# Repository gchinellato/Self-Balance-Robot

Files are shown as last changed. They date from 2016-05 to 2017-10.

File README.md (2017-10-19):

# Mr. Robot
_DIY study project_

## Description
Mr. Robot is an amazing TV series \o/, but also it is a DIY project based on the self balance robot concept using sensors to get orientation (pitch, roll and yaw) and PID controller to set the motor speed. Beside that, there are some additional features like wireless controllers by IP or bluetooth clients, computer vision functions like object tracking, video streaming to be used such as Google Cardboard VR for Android application and upcoming features.

## Study topics
This project is based on the following topics:
* Raspberry PI     
* Linux OS
* Python programming
* C++ programming
* Multithread/Multiprocess programming
* Robotics concepts
* IMU sensor fusion
* Computer Vision
* Communication protocols (UART, I2C, SPI, TCP, UDP...)
* Android app (*)
* PyQT

## Item list
* Raspberry Pi 3
* Arduino Nano Atmega328
* PiCam
* Pan/Tilt kit with micro servo 9g
* IMU GY80 10DOF sensor
* Ultrasonic HC-SR04 sensor (*)
* DC gearmotor 29:1 with encoder 12V 365RPM 8KgF.cm 
* Shaft coupler
* Wheels 1/8 buggy
* VNH2SP30 motor driver (H-bridge)
* LiPo battery 3S 11.1 2200mAh
* DC-DC Step down converter
* Bluetooth dongle
* WiFi dongle   
* Google Cardboard VR (*)
* Screws, nuts and bolts
* Acrylic frames 20x15x8cm

(*) TBD 

## External tools
* Opencv: http://opencv.org/
* pySerial: https://github.com/pyserial/pyserial
* PyQt5: https://sourceforge.net/projects/pyqt/
* PyOpenGL: http://pyopengl.sourceforge.net/
* matplotlib: http://matplotlib.org/
* PS3 Bluetooth Controller driver: http://qtsixa.sourceforge.net/
* Servoblaster: https://github.com/richardghirst/PiBits/tree/master/ServoBlaster
* PlatformIO: http://platformio.org/
* Atom IDE: https://atom.io/

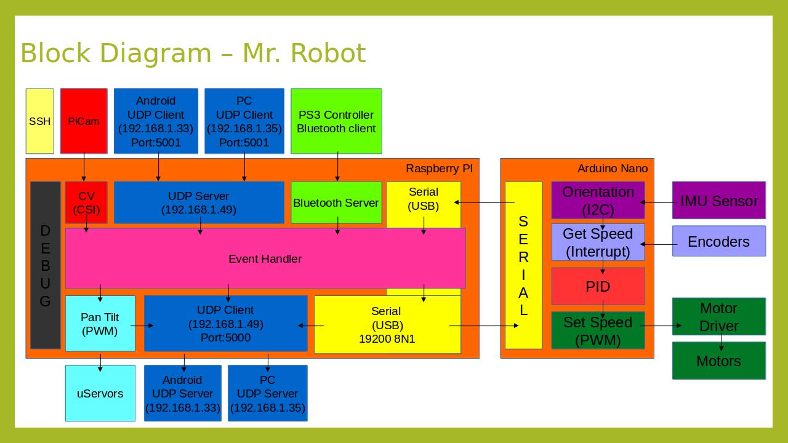
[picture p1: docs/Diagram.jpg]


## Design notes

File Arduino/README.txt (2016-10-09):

# Arduino Nano

Instantiate Motors objects
Instantiate Encoder objetcs
Instantiate PID objects
Instantiate IMU objects (Accel, Gyro, Magno, Barom)

setup()
{
    Configure serial
    Configure interrup pins
    Set configuration
}

loop()
{
    Read serial trace
    Read sensors
    Sensor fusion (Euler angles)   
    Update speeds
    Compute speed PID
    Check angle
    Define PID mode
    Compute angle PID
    Motor set speed
    Send serial trace  
}

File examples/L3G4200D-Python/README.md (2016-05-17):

L3G4200D-Python
===============

L3G4200D Gyro interface in python, using I2C.

Currently, this code opens port i2c-1 in /dev and imports raw data(signed int) of each gyro axis.
you must have python installed "apt-get install python"
in command line do "python gyro.py" to stream raw axis data from the gyro. the readings are noisy, and that's normal.

you should get something like this:

        -1        -14          6
         4        -15          5
        -1        -15         10
        -4        -19          4
        -2        -15         11
         2        -19          7
         1        -17         10
         8        -15         10
         5        -16          7
         2        -17          6
         0        -18         10
        -2        -16         14

you can type "python gyro.py > data.tsv", then ctrl C to stop. take data.tsv, open it in MS Excel
or equivelant, and plot the data to visualise the gyro movements.

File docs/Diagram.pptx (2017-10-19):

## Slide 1

Mr. Robot

Self Balance Robot

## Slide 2

Block Diagram – Mr. Robot

SSH

D
E
B
U
G

PiCam

CV
(CSI)

Android
UDP Client
(192.168.1.33)
Port:5001

PC
UDP Client
(192.168.1.35)
Port:5001

PS3 Controller
Bluetooth client

Bluetooth Server

Raspberry PI

Event Handler

UDP Server
(192.168.1.49)

Serial
(USB)

Serial
(USB)
19200 8N1

Arduino Nano

Orientation
(I2C)

Get Speed
(Interrupt)

PID

Set Speed
(PWM)

S
E
R
I
A
L

IMU Sensor

Encoders

Pan Tilt
(PWM)

UDP Client
(192.168.1.49)
Port:5000

Motor
Driver

uServors

Android
UDP Server
(192.168.1.33)

PC
UDP Server
(192.168.1.35)

Motors

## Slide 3

Block Diagram – Wifi Monitor

RPI
UDP Client
(192.168.1.49)

PC

UDP Server
(192.168.1.35)
PORT:5000

UDP Client
(192.168.1.49)
Port:5001

GUI
PyQT

Real time graph
Matplotlib

3D Model
OpenGL

RPI
UDP Server
(192.168.1.49)

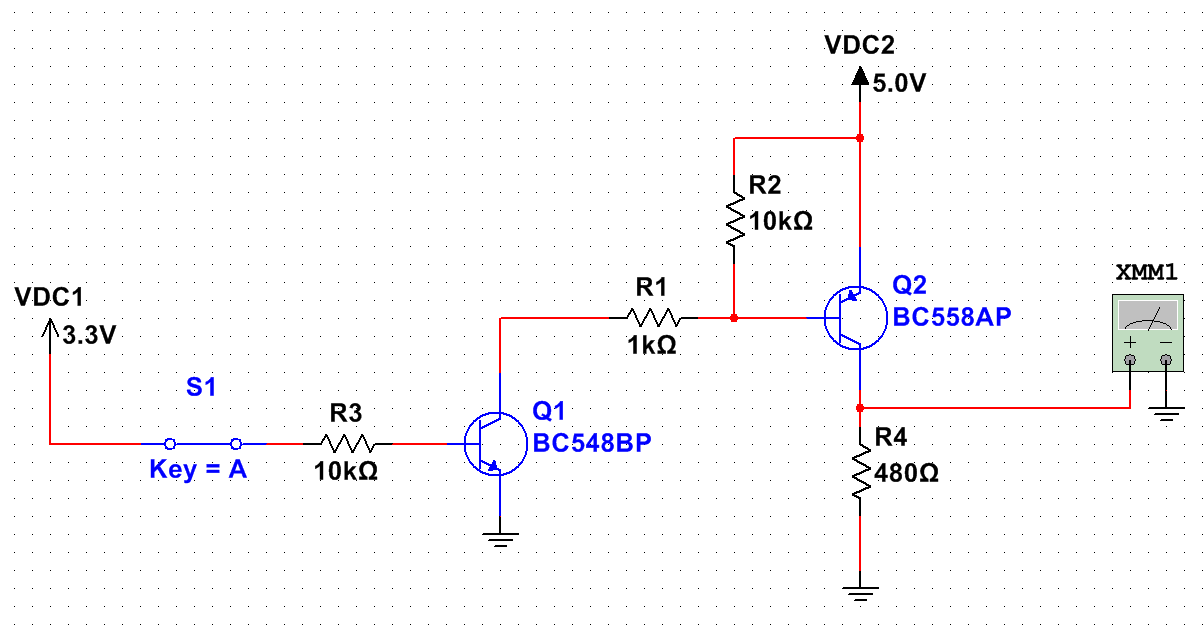
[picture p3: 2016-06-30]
docs/transistor-switch.png

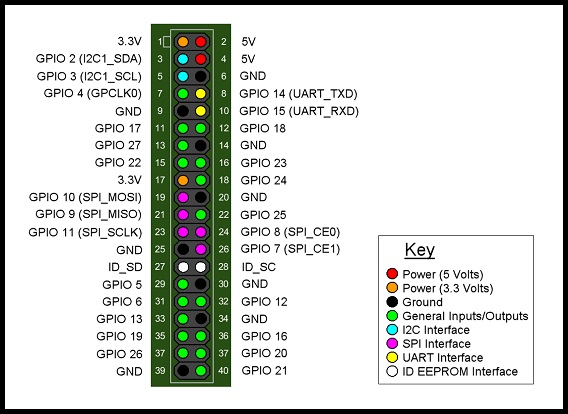
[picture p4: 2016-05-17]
docs/raspberrypi2-gpio-mapping.jpg

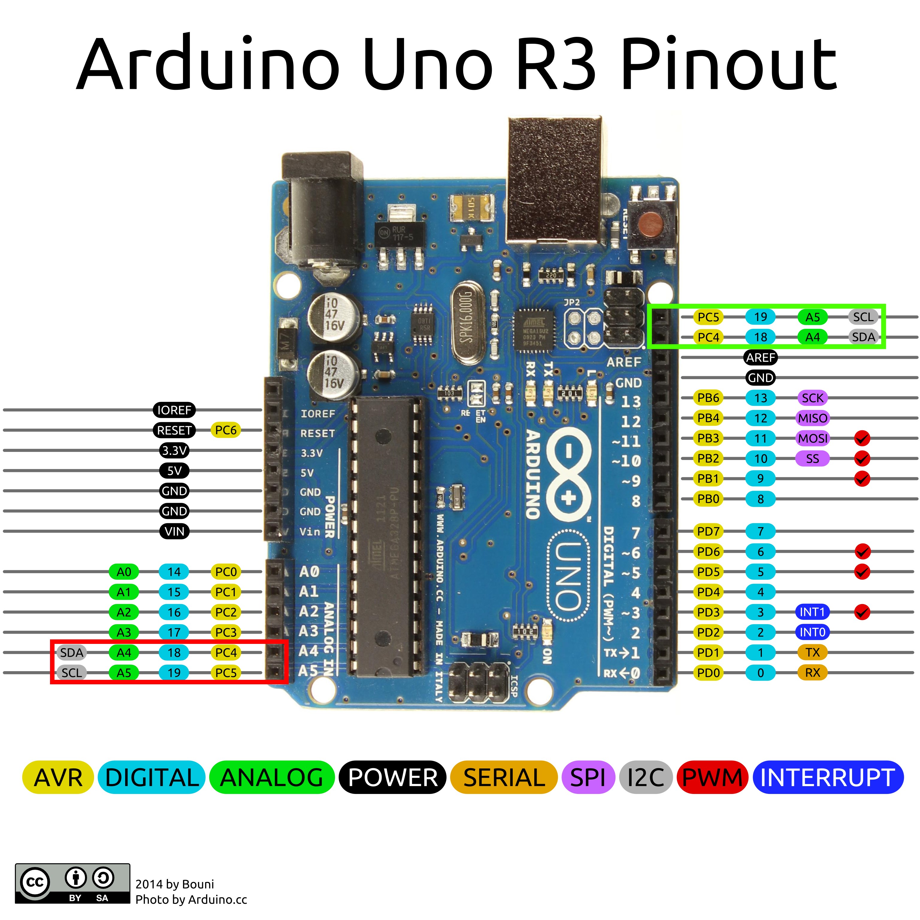
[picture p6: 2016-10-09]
docs/arduino-uno-r3-gpio-mapping.jpg

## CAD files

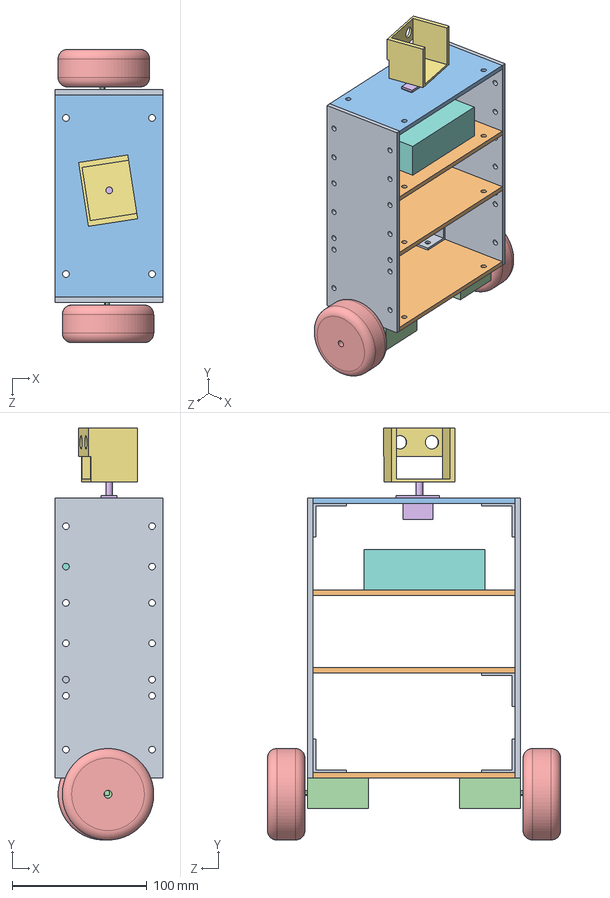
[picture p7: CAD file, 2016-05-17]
3D Model/Frame.SLDASM
80.0 x 306.2 x 218.0 mm
Placa-lateral x 2
Placa-inferior x 3
Placa-superior
motor x 2
roda x 2
micro-servo
pan-tilt
rp2
Suporte-L x 5

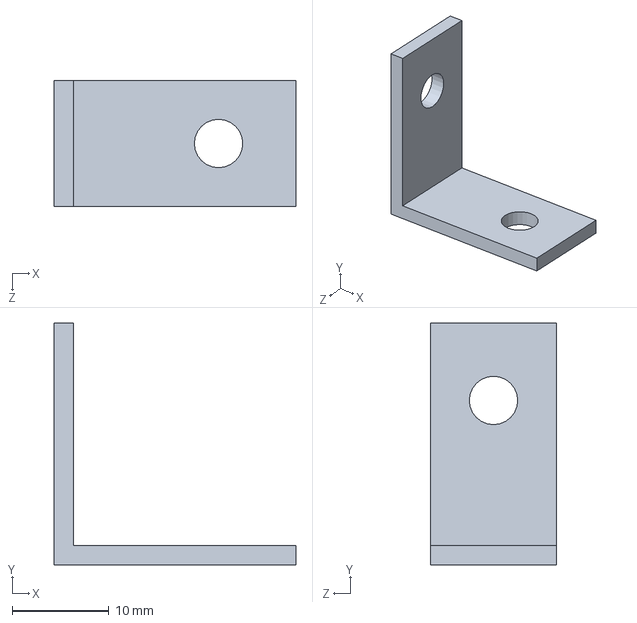
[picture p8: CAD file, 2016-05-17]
3D Model/Suporte-L.SLDPRT
25.0 x 25.0 x 13.0 mm

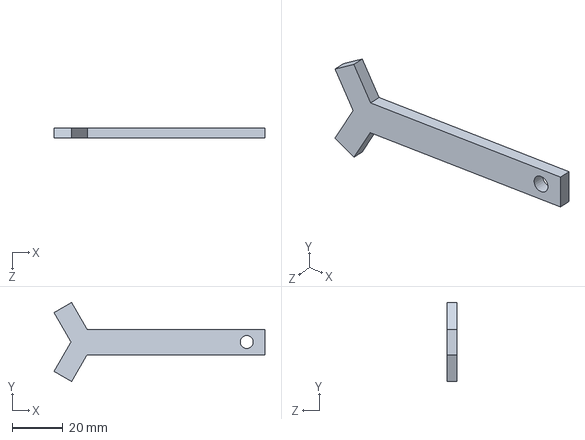
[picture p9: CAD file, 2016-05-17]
3D Model/arm.SLDPRT
82.9 x 31.1 x 4.00 mm

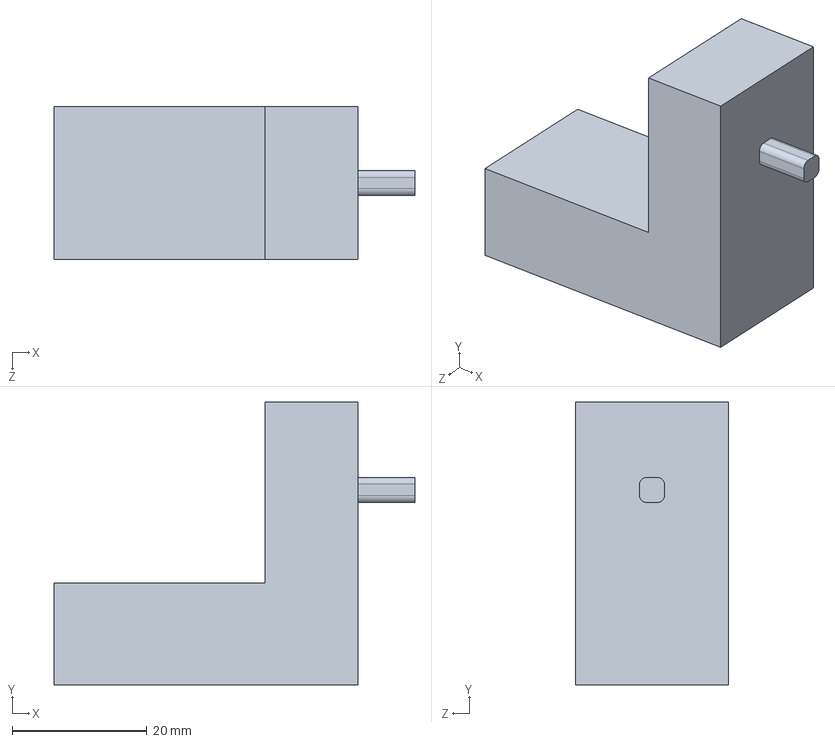
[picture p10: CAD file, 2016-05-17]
3D Model/motor.SLDPRT
53.6 x 42.0 x 22.7 mm

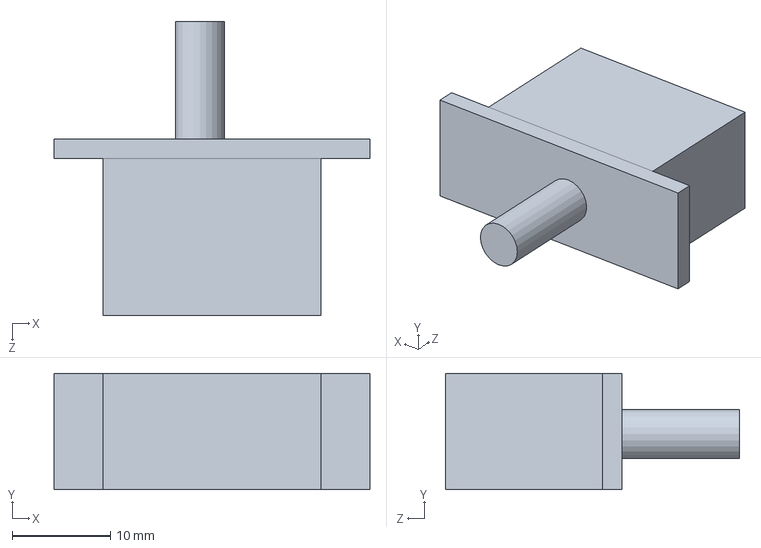
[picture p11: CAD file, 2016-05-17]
3D Model/micro-servo.SLDPRT
32.2 x 11.8 x 30.0 mm

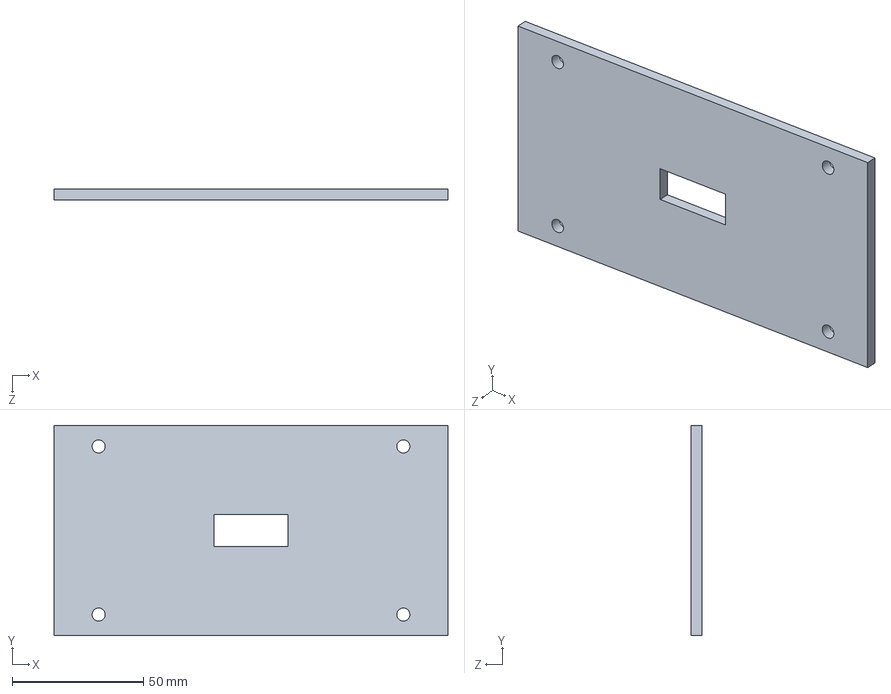
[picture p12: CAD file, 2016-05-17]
3D Model/Placa-superior.SLDPRT
150.0 x 80.0 x 4.00 mm

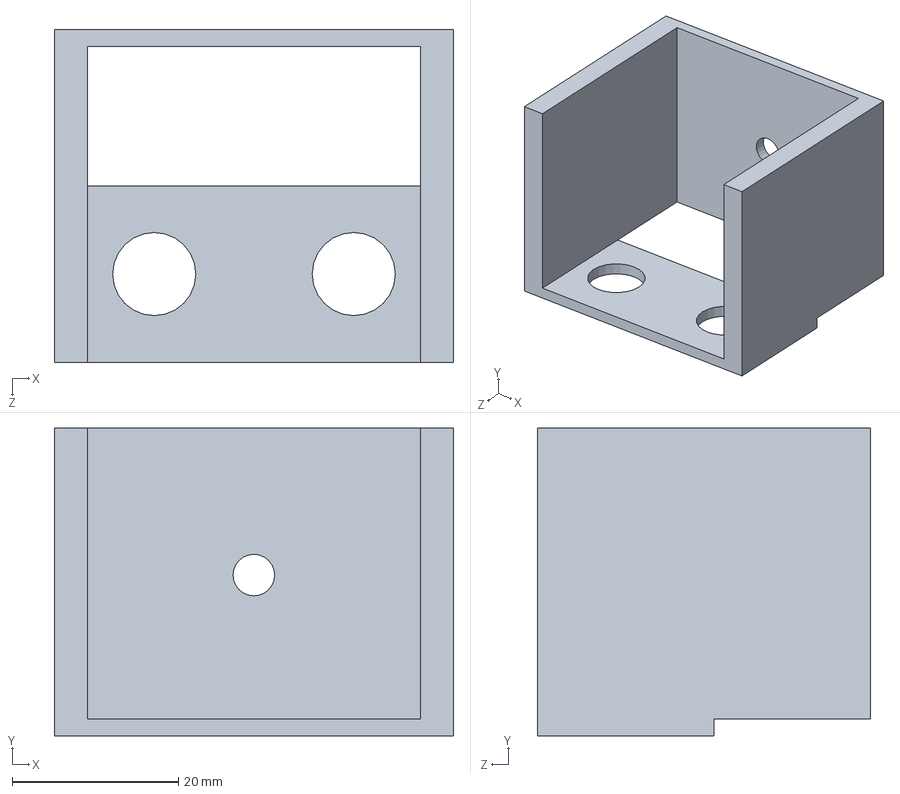
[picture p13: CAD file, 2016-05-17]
3D Model/pan-tilt.SLDPRT
48.0 x 37.0 x 40.0 mm

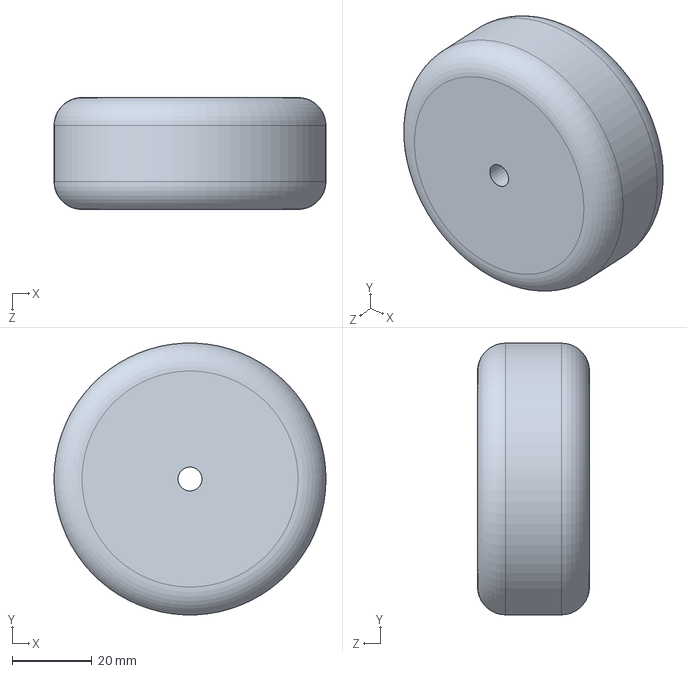
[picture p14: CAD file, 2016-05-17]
3D Model/roda.SLDPRT
68.0 x 67.9 x 28.0 mm

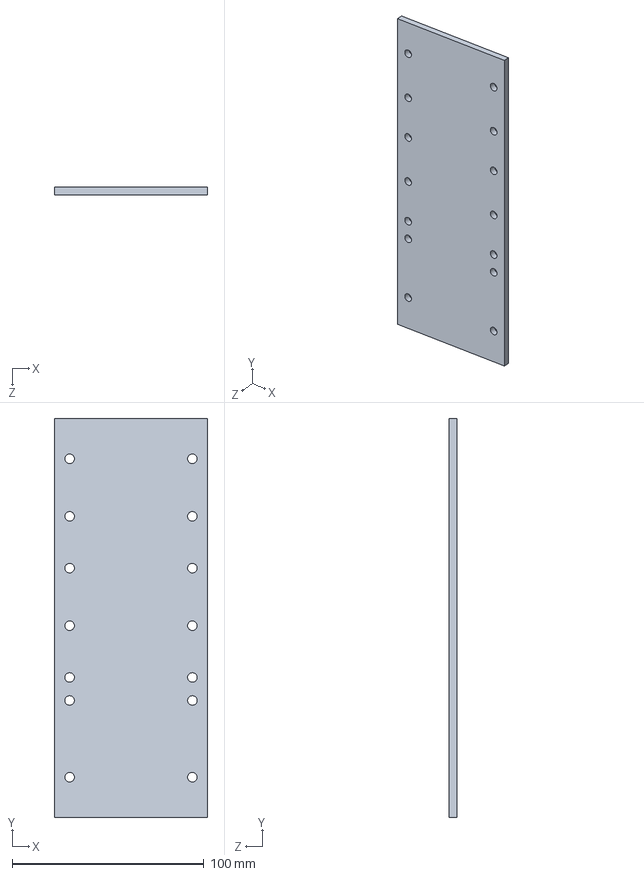
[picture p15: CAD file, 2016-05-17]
3D Model/Placa-lateral.SLDPRT
80.0 x 208.0 x 4.00 mm

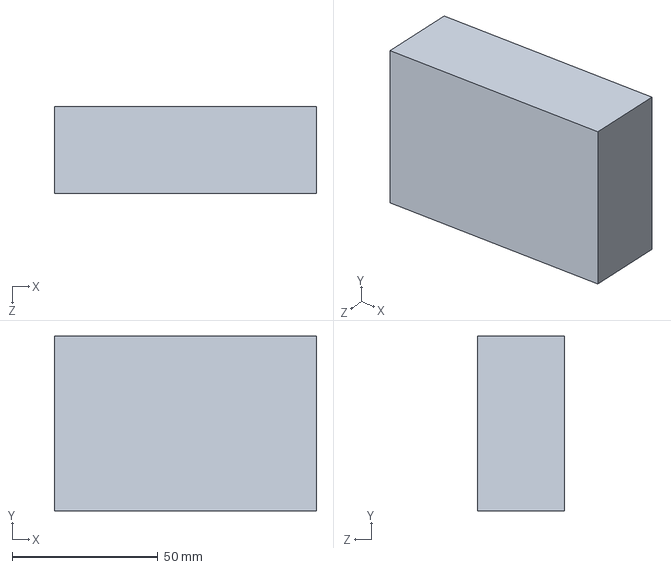
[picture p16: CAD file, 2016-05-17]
3D Model/rp2.SLDPRT
90.0 x 60.0 x 30.0 mm

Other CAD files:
3D Model/Placa-inferior.SLDPRT
3D Model/Placa-inferior.SLDDRW
3D Model/Placa-lateral.SLDDRW
3D Model/Placa-superior.SLDDRW

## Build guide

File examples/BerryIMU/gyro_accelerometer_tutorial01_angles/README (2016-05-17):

* Developed by Mark Williams
* Created December 2014

This program will enable your Raspberry Pi to read the values from a gyroscope and accelerometer and convert them to usable angles.
Go here for more information;

http://ozzmaker.com/2014/12/11/berryimu/

Compile with;
gcc -o gyro_accelerometer_tutorial01 -l rt gyro_accelerometer_tutorial01.c -lm

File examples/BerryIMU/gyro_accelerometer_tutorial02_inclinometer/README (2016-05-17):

* Developed by Mark Williams
* Created December 2014

This program is used to create an Inclinometer using a Raspberry Pi and an IMU

http://ozzmaker.com/2014/12/12/inclinometer-using-raspberry-pi-imu/

Compile with;

gcc -o gyro_accelerometer_tutorial02 -lm gyro_accelerometer_tutorial02.c `sdl-config --cflags` `sdl-config --libs` -lSDL_image -lSDL_gfx

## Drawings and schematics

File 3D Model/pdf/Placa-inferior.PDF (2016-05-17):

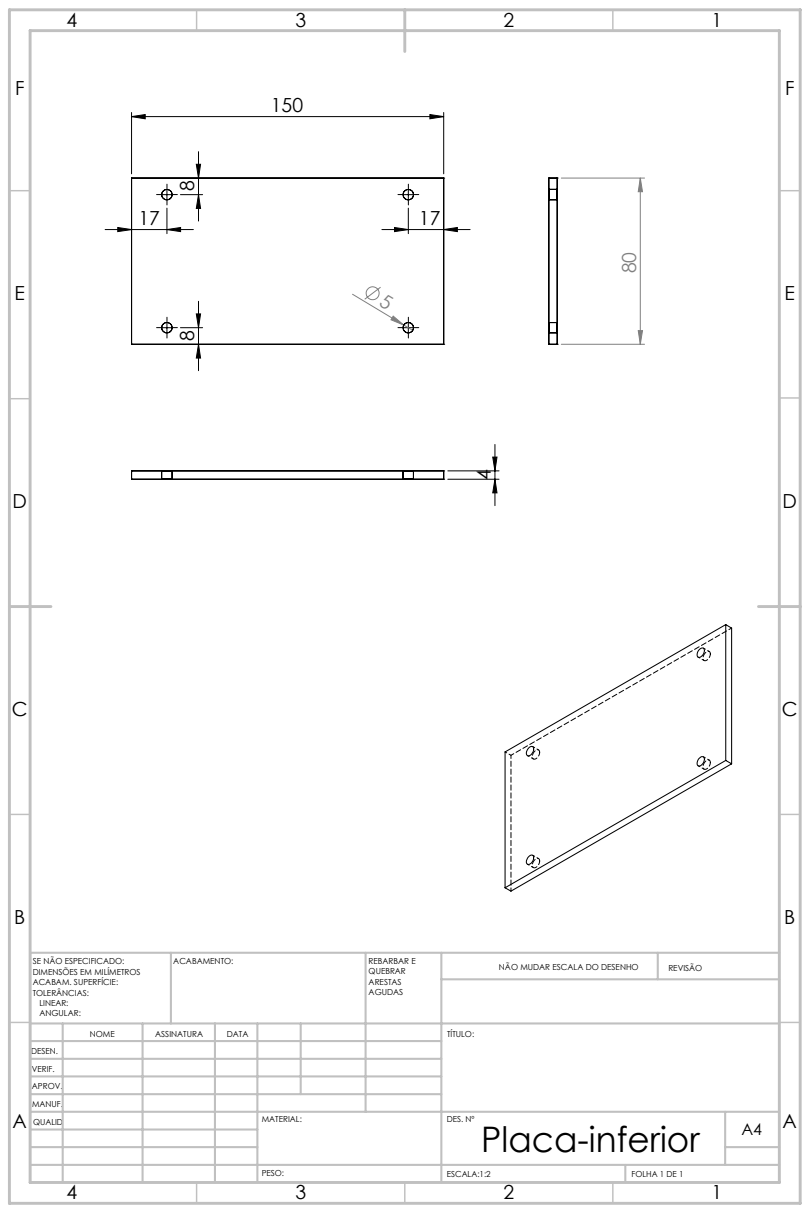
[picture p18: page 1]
ACABAMENTO:; REBARBAR E; NÃO MUDAR ESCALA DO DESENHO; REVISÃO; ESCALA:1:2; FOLHA 1 DE 1

SE NÃO ESPECIFICADO:
DIMENSÕES EM MILÍMETROS
ACABAM. SUPERFÍCIE:
TOLERÂNCIAS:
LINEAR:
ANGULAR:

NOME | ASSINATURA | DATA | | | | TÍTULO:

DESEN.
VERIF.
APROV.
MANUF.
QUALID | | | | MATERIAL: | DES. Nº Placa-inferior | A4

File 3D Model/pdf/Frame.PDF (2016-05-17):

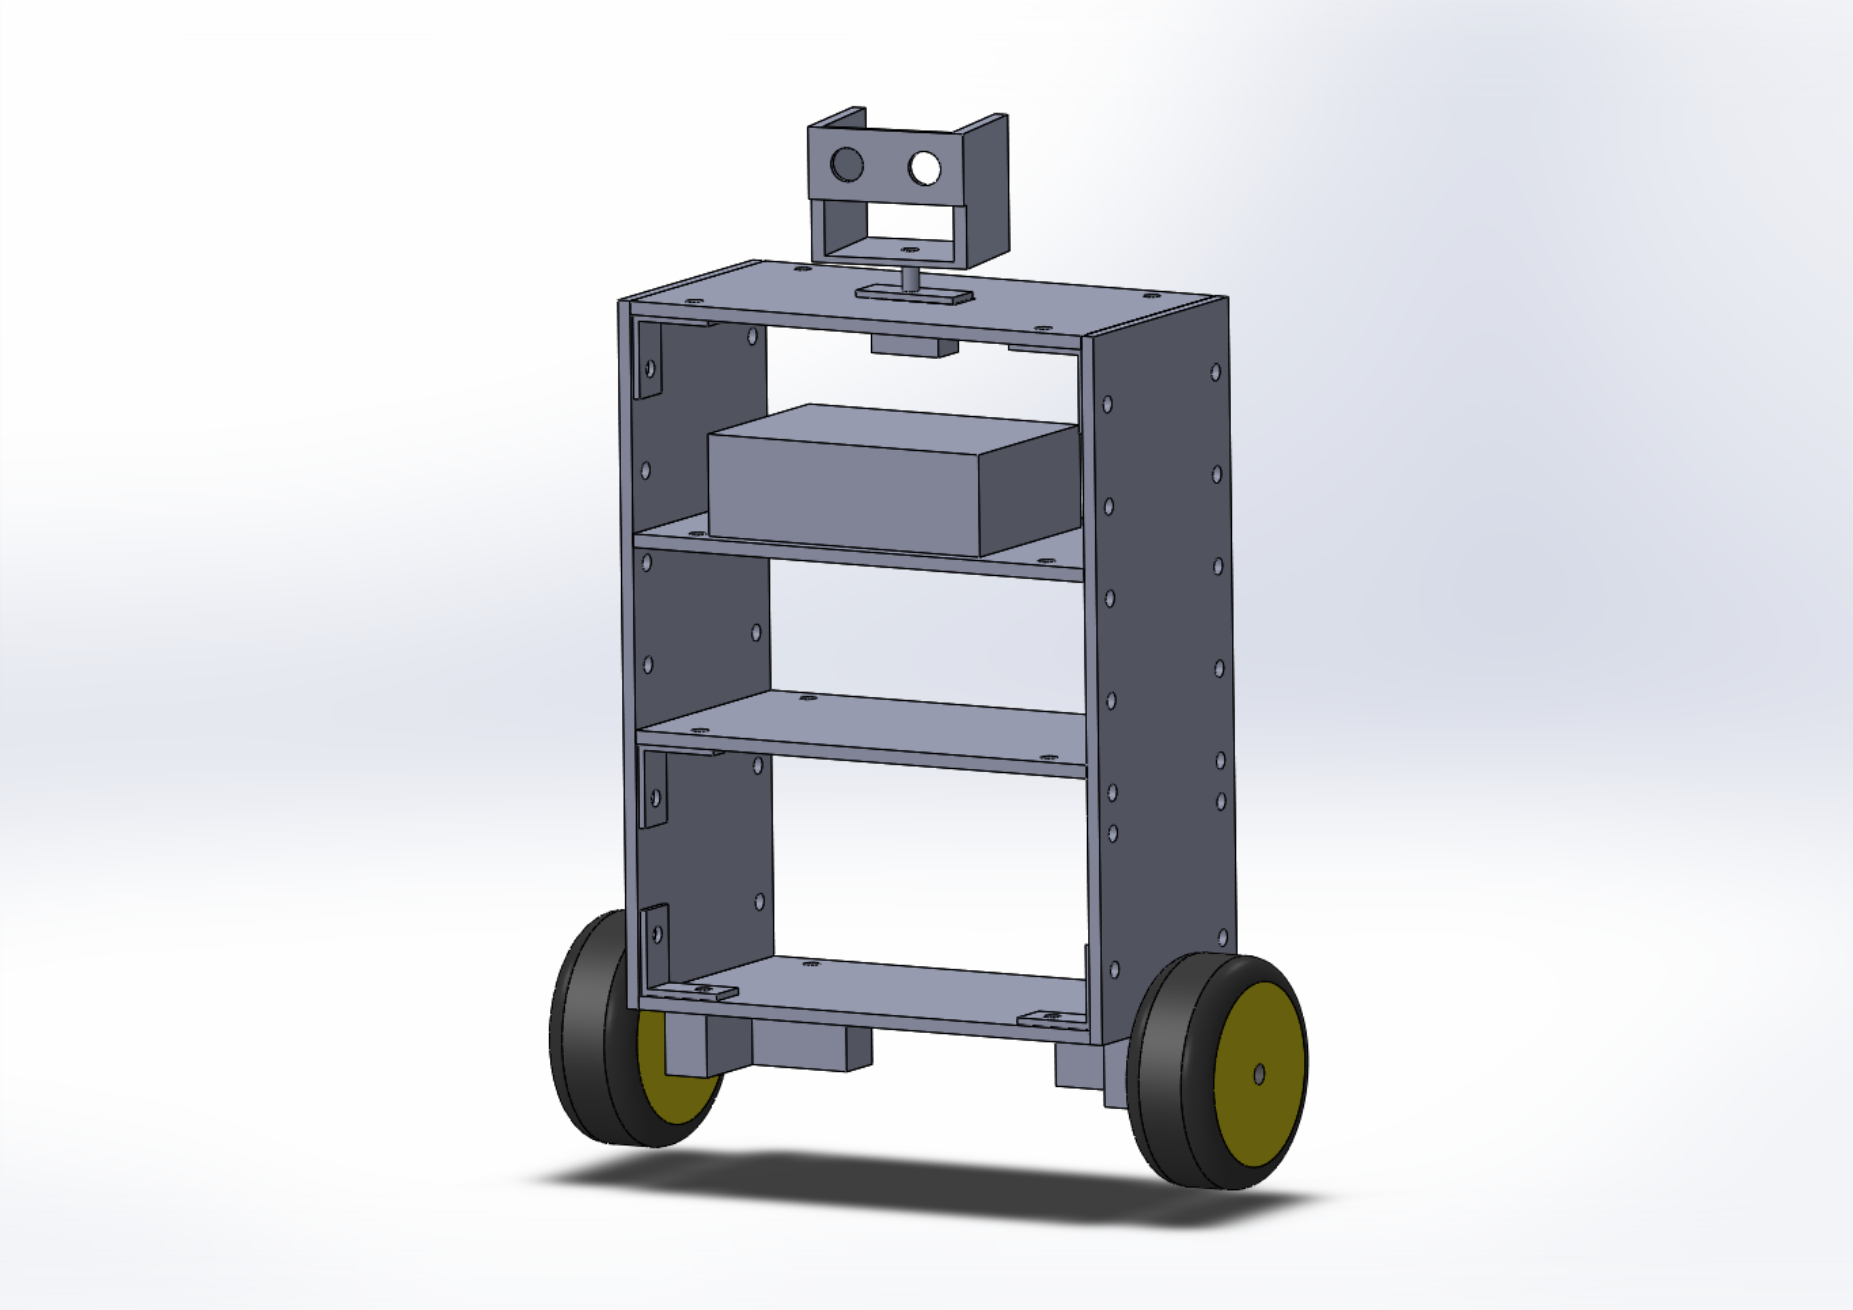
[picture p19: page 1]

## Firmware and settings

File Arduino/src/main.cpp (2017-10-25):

/**
*************************************************
* @Project: Self Balance
* @Platform: Arduino Nano ATmega328
* @Description: Main thread
* @Owner: Guilherme Chinellato
* @Email: guilhermechinellato@gmail.com
*************************************************
*/

#include "Arduino.h"
#include <string.h>
#include <Wire.h>
#include "IMU/GY80.h"
#include "Motion/Motor/motor.h"
#include "Motion/Encoder/encoder.h"
#include "Motion/PID/PID.h"
#include "main.h"

Configuration configuration;
UserControl userControl = {0, 0};

// PID variables
float anglePIDSetpoint, anglePIDInput, anglePIDOutput;
float speedPIDInput, speedPIDOutput, speedPIDSetpoint;

float lastDistance1 = 0, lastDistance2 = 0;

// start and stop flag
boolean started = false;

//PID objects
PID speedPID;
PID anglePID;
PIDTuning activePIDTuning = CONSERVATIVE;

//Motors objects
Motor motor1(PWM1_PIN,CW1_PIN,CCW1_PIN,CS1_PIN);
Motor motor2(PWM2_PIN,CW2_PIN,CCW2_PIN,CS2_PIN);

//Encoder objects
Encoder encoder1(ENCODERA1_PIN,ENCODERB1_PIN);
Encoder encoder2(ENCODERA2_PIN,ENCODERB2_PIN);

/* interrupt functions for counting revolutions in the encoders */
/*when the callback function is called due an interrup event on pinEncoder1 and pinEncoder2 is true, then is clockwise, if not it is counter-clockwise*/
void encoderISR1()
{
    if(digitalRead(encoder1.pin2)){ encoder1.ticks++; }
    else{ encoder1.ticks--; }
}

void encoderISR2()
{
    if(digitalRead(encoder2.pin2)){ encoder2.ticks++; }
    else{ encoder2.ticks--; }
}

void setConfiguration()
{
    configuration.speedPIDKp = SPEED_KP;
    configuration.speedPIDKi = SPEED_KI;
    configuration.speedPIDKd = SPEED_KD;
    configuration.speedPIDOutputLowerLimit = -10.00;
    configuration.speedPIDOutputHigherLimit = 10.00;
    configuration.anglePIDAggKp = ANGLE_KP_AGGR;
    configuration.anglePIDAggKi = ANGLE_KI_AGGR;
    configuration.anglePIDAggKd = ANGLE_KD_AGGR;
    configuration.anglePIDConKp = ANGLE_KP_CONS;
    configuration.anglePIDConKi = ANGLE_KI_CONS;
    configuration.anglePIDConKd = ANGLE_KD_CONS;
    configuration.anglePIDLowerLimit = ANGLE_LIMIT;
    configuration.calibratedZeroAngle = CALIBRATED_ZERO_ANGLE;
}

void setup()
{
    Serial.begin(SERIAL_BAUDRATE);
    Serial.setTimeout(10);
    while(!Serial) {}

    //Caution: beware to change TIMER0 default register.
    //Millis, delay and other functions uses the same TIMER0 as PWM pin 5 and 6.
    //Check https://arduino-info.wikispaces.com/Arduino-PWM-Frequency
    //define PWM pre-scaler to 3921.16 Hz in TIMER1
    TCCR1B = (TCCR1B & B11111000) | B00000010;

    //interrupt pins
    pinMode(encoder1.pin1, INPUT_PULLUP);
    pinMode(encoder2.pin1, INPUT_PULLUP);
    attachInterrupt(digitalPinToInterrupt(encoder1.pin1), encoderISR1, RISING);
    attachInterrupt(digitalPinToInterrupt(encoder2.pin1), encoderISR2, RISING);

    setConfiguration();

/*
    GY80 imu;
	if (CALIBRATION_MAGNETO == 1)
	{
		Serial.println("MAGNETO/1000.0fMETER CALIBRATION STARTED");
		imu.magCalibration();
		Serial.println("CALIBRATION FINISHED");
	}
*/
}

void loop()
{
    float velocity1=0, velocity2=0;
    float distance1, distance2;
    int command = 0;
    String msg;
    char buff[128];
    char *ret;
    int size;

    GY80 imu;

    while(1)
	{
        timestamp = millis();
        if ((timestamp - timestamp_old) >= DATA_INTERVAL)
		{    
            //convert from ms to sec
            dt = (float)(timestamp - timestamp_old)/1000.0f; 
            timestamp_old = timestamp;

            msg = "";
            //read serial trace
            //(TRACE_BEGIN)(COMMAND),(NUM_PARAM),(PARAM_1),(PARAM_2),(...)(TRACE_END)
            while(Serial.available() > 0)
            {
                // read the incoming byte:
                msg = Serial.readString();
                //Serial.print(msg);
            }

            if(msg != ""){
                //valid packet? Start: #BEGIN# End: #END#\r\n
                if(msg.startsWith(TRACE_BEGIN) && msg.endsWith(TRACE_END+String("\r\n"))){
                    //remove TRACE_BEGIN
                    msg.remove(0,7);

                    //remove TRACE_END\r\n
                    msg.remove(msg.length()-7,7);

                    //conver75t from string to char array
                    msg.toCharArray(buff, 128);

                    //split string into tokens
                    ret = strtok(buff, ",");

                    //get command
                    command = atoi(ret);
                    //get number of parameters
                    size = int(strtok(NULL, ","));

                    switch (command) {
                        case STARTED:
                            started = atoi(strtok(NULL, ","));
                            //Serial.println("STARTED command: " + String(started));
                            break;
                        case DIRECTION:
                            userControl.direction = atof(strtok(NULL, ","));
                            userControl.direction /= 10;
                            //Serial.println("DIRECTION command: " + String(userControl.direction));
                            break;
                        case STEERING:
                            userControl.steering = atof(strtok(NULL, ","));
                            userControl.steering /= 10;
                            //Serial.println("STEERING command: " + String(userControl.steering));
                            break;
                        case SPEED_PID:
                            configuration.speedPIDKp = atof(strtok(NULL, ","));
                            configuration.speedPIDKi = atof(strtok(NULL, ","));
                            configuration.speedPIDKd = atof(strtok(NULL, ","));
                            //Serial.println("SPEED_PID command: " + String(configuration.speedPIDKp) +","+ String(configuration.speedPIDKi) +","+ String(configuration.speedPIDKd));
                            speedPID.setTunings(configuration.speedPIDKp, configuration.speedPIDKi, configuration.speedPIDKd);
                            break;
                        case ANGLE_PID_AGGR:
                            configuration.anglePIDAggKp = atof(strtok(NULL, ","));
                            configuration.anglePIDAggKi = atof(strtok(NULL, ","));
                            configuration.anglePIDAggKd = atof(strtok(NULL, ","));
                            //Serial.println("ANGLE_PID_AGGR command: " + String(configuration.anglePIDAggKp) +","+ String(configuration.anglePIDAggKi) +","+ String(configuration.anglePIDAggKd));
                            break;
                        case ANGLE_PID_CONS:
                            configuration.anglePIDConKp = atof(strtok(NULL, ","));
                            configuration.anglePIDConKi = atof(strtok(NULL, ","));
                            configuration.anglePIDConKd = atof(strtok(NULL, ","));
                            //Serial.println("ANGLE_PID_CONS command: " + String(configuration.anglePIDConKp) +","+ String(configuration.anglePIDConKi) +","+ String(configuration.anglePIDConKd));
                            break;
                        case ZERO_ANGLE:
                            configuration.calibratedZeroAngle = atof(strtok(NULL, ","));
                            //Serial.println("ZERO_ANGLE command: " + String(configuration.calibratedZeroAngle));
                            break;
                        case ANGLE_LIMITE:
                            configuration.anglePIDLowerLimit = atof(strtok(NULL, ","));
                            //Serial.println("ANGLE_LIMITE command: " + String(configuration.anglePIDLowerLimit));
                            break;
                        default:
                            //Serial.println("Unknown command");
                            break;
                    }
                }
                else{
                    //Invalid packtet
                    //Serial.println("Invalid packtet");
                }
            }

            //read sensors and calculate Euler Angles
			ori = imu.getOrientation(1, dt); //roll pitch yaw
            anglePIDInput = ori[1];

            //update velocity
            //velocity: derivative of position (Pf - Pi)/dt, from cm/ms to m/s
            if(dt > 0)
            {
                distance1 = encoder1.getDistance();
                distance2 = encoder2.getDistance();
                velocity1 = ((distance1 - lastDistance1)*0.01)/(dt/1000.0);
                velocity2 = ((distance2 - lastDistance2)*0.01)/(dt/1000.0);
                lastDistance1 = distance1;
                lastDistance2 = distance2;
            }

            //update motor speed
            motor1.motorSpeed = (float)(encoder1.ticks - encoder1.lastTicks);
            encoder1.lastTicks = encoder1.ticks;
            motor2.motorSpeed = (float)(encoder2.ticks - encoder2.lastTicks);
            encoder2.lastTicks = encoder2.ticks;
/*
            //Compute Speed PID (input is wheel speed. output is angleSetpoint)
            speedPIDInput = (motor1.motorSpeed + motor2.motorSpeed)/2;
            speedPID.setSetpoint(userControl.direction);
            speedPIDOutput = speedPID.compute(speedPIDInput);

            //set angle setpoint and compensate to reach equilibrium point
            anglePID.setSetpoint(speedPIDOutput+configuration.calibratedZeroAngle);

            // update angle pid tuning. only update if different from current tuning
    		if((activePIDTuning == AGGRESSIVE) && (abs(anglePIDInput) < configuration.anglePIDLowerLimit)) {
    			//we're close to setpoint, use conservative tuning parameters
    			activePIDTuning = CONSERVATIVE;
    			anglePID.setTunings(configuration.anglePIDConKp, configuration.anglePIDConKi, configuration.anglePIDConKd);
    		}
    		else if ((activePIDTuning == CONSERVATIVE) && (abs(anglePIDInput) >= configuration.anglePIDLowerLimit)) {
    			//we're far from setpoint, use aggressive tuning parameters
    			activePIDTuning = AGGRESSIVE;
    			anglePID.setTunings(configuration.anglePIDAggKp, configuration.anglePIDAggKi, configuration.anglePIDAggKd);
    		}
    		else if (abs(anglePIDInput) > ANGLE_IRRECOVERABLE){
    			// so sorry, we're licking the floor :(
    			started = false;
    		}

            // Compute Angle PID (input is current angle, output is angleSetpoint)
    		anglePIDOutput = anglePID.compute(anglePIDInput);
            //Serial.println("Pitch: " + String(anglePIDInput) + ", anglePIDOutput: " + String(anglePIDOutput));
*/
            //Set angle setpoint and compensate to reach equilibrium point
            anglePID.setSetpoint(userControl.direction+configuration.calibratedZeroAngle);
            anglePID.setTunings(configuration.anglePIDConKp, configuration.anglePIDConKi, configuration.anglePIDConKd);
            //Compute Angle PID (input is current angle)
            anglePIDOutput = anglePID.compute(anglePIDInput);

            //Set PWM value
            if (started && (abs(anglePIDInput) < ANGLE_IRRECOVERABLE)) {
                //compensate dead band
                /*if(anglePIDOutput >= 0) {
                    anglePIDOutput += DEAD_BAND;
                }else {
                    anglePIDOutput -= DEAD_BAND;
                }*/

                motor1.setSpeedPercentage(anglePIDOutput+userControl.steering);
                motor2.setSpeedPercentage(anglePIDOutput-userControl.steering);
            }
            else {
                motor1.motorOff();
                motor2.motorOff();
            }

            //write serial trace
            Serial.println(TRACE_BEGIN + \
						   String(timestamp) + "," + \
						   String(dt) + "," + \
                           String(ori[0],1) + "," + \
                           String(ori[1],1) + "," + \
                           String(ori[2],1) + "," + \
                           /*String(encoder1.ticks) + "," + \
                           String(encoder2.ticks) + "," + \
                           String(distance1) + "," + \
                           String(distance2) + "," + \
                           String(velocity1) + "," + \
                           String(velocity2) + "," + \
                           String(motor1.motorSpeed) + "," + \
                           String(motor2.motorSpeed) + "," + \
                           String(speedPIDOutput) + "," + \*/
                           String(anglePID.getSetpoint()) + "," + \
                           String(anglePIDOutput) + "," + \
                           String(userControl.direction) + "," + \
                           String(userControl.steering) + \
                           TRACE_END);
        }
	}
}

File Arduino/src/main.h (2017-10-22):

/**
*************************************************
* @Project: Self Balance
* @Platform: Arduino Nano ATmega328
* @Description: Main thread
* @Owner: Guilherme Chinellato
* @Email: guilhermechinellato@gmail.com
*************************************************
*/

#ifndef MAIN_H
#define MAIN_H

#define SERIAL_BAUDRATE 	19200
#define CALIBRATION_MAGNETO	0
#define DATA_INTERVAL 	    10 // ms

/* GPIO mapping */

#define PWM1_PIN 9
#define CW1_PIN 5
#define CCW1_PIN 11
#define CS1_PIN 2

#define PWM2_PIN 10
#define CW2_PIN 6
#define CCW2_PIN 12
#define CS2_PIN 3

#define ENCODERA1_PIN 2
#define ENCODERB1_PIN 4
#define ENCODERA2_PIN 3
#define ENCODERB2_PIN 7

#define TRACE_BEGIN "#BEGIN#"
#define TRACE_END "#END#"

enum cmd{
	STARTED = 0,
	DIRECTION,
	STEERING,
	SPEED_PID,
	ANGLE_PID_AGGR,
	ANGLE_PID_CONS,
	ZERO_ANGLE,
	ANGLE_LIMITE
};

float dt=0; // duration time
unsigned long timestamp=0;
unsigned long timestamp_old=0;
float *ori; // orientation vector (roll, pitch, yaw)

struct Configuration {
	double speedPIDKp;
	double speedPIDKi;
	double speedPIDKd;
	double speedPIDOutputLowerLimit;
	double speedPIDOutputHigherLimit;
	double anglePIDAggKp;
	double anglePIDAggKi;
	double anglePIDAggKd;
	double anglePIDConKp;
	double anglePIDConKi;
	double anglePIDConKd;
	double anglePIDLowerLimit;
	double calibratedZeroAngle;
	int motor1MinimumSpeed;
	int motor2MinimumSpeed;
};

struct UserControl {
	float steering;
	float direction;
};

void setConfiguration();

#endif

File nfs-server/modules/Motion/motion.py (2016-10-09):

#!/usr/bin/python
"""
*************************************************
* @Project: Self Balance  
* @Platform: Raspberry PI 2 B+                       
* @Description: Motion 
*               DC Motor with gearbox/encoder
*               Motor driver VNH2SP30
* @Owner: Guilherme Chinellato 
* @Email: guilhermechinellato@gmail.com                                                
*************************************************
"""

import time
from Motion.Motor.motor import Motor
from Motion.Encoder.encoder import Encoder
from constants import *
from Utils.gpio_mapping import *
from Utils.traces.trace import *

class Motion():
    def __init__(self, debug=0):
        self.debug = debug

        self._motorA = Motor("Left", MA_PWM_GPIO, MA_CLOCKWISE_GPIO, MA_ANTICLOCKWISE_GPIO, debug) 
        self._motorB = Motor("Right", MB_PWM_GPIO, MB_CLOCKWISE_GPIO, MB_ANTICLOCKWISE_GPIO, debug) 

        self._encoderA = Encoder("Left", MA_ENCODER_1, MA_ENCODER_2, TICKS_PER_TURN, WHEEL_RADIUS, debug)
        self._encoderB = Encoder("Right", MB_ENCODER_1, MB_ENCODER_2, TICKS_PER_TURN, WHEEL_RADIUS, debug)

        self.wheelVelocityAvg = 0
        self.wheelVelocityA = 0
        self.wheelVelocityB = 0
        self.lastWheelPositionA = 0
        self.lastWheelPositionB = 0

        #Start motor PWM
        self.motorStart()

        logging.info("Motion Module initialized") 

    def updateWheelVelocity(self, dt=1.0):
        '''wheelPosition = self.getWheelPosition()
        #velocity: derivative of position (Pf - Pi)/dt
        if (dt > 0):
            self.wheelVelocity = (wheelPosition - self.lastWheelPosition)/dt
        self.lastWheelPosition = wheelPosition'''

        wheelDistanceA, wheelDistanceB = self.getDistance()
        #velocity: derivative of position (Pf - Pi)/dt
        if (dt > 0):
            self.wheelVelocityA = (wheelDistanceA - self.lastWheelPositionA)/dt
            self.wheelVelocityB = (wheelDistanceB - self.lastWheelPositionB)/dt
        self.lastWheelPositionA = wheelDistanceA
        self.lastWheelPositionB = wheelDistanceB

        self.wheelVelocityAvg = (self.wheelVelocityA+self.wheelVelocityB)/2

        if (self.debug & MODULE_MOTION):
            logging.debug(("wheelVelocity Average: %0.2f, A: %0.2f, B: %0.2f" % (self.wheelVelocityAvg, self.wheelVelocityA, self.wheelVelocityB)))

    def getWheelVelocity(self):
        if (self.debug & MODULE_MOTION):
            logging.debug(("wheelVelocity : [%0.2f cm/s] [%0.2f m/s] [%0.2f km/h]" % (self.wheelVelocityAvg, self.wheelVelocityAvg/100, (self.wheelVelocityAvg/100)*3.6)))
        return self.wheelVelocityAvg

    def getDistance(self):
        '''Get distance from each motor, should be similar'''
        return (self._encoderA.getDistance(), self._encoderB.getDistance())
        #return self._encoderA.getDistance()

    def getWheelPosition(self):
        #return self._encoderA.getTicks() + self._encoderB.getTicks()
        return (self._encoderA.getTicks(), self._encoderA.getTicks())

    def motorMove(self, speedA, speedB):
        '''Set motor speed, checking the boundaries and adding compensations for each motor (if necessary)'''
        limitedSpeedA = self._constraint(abs(speedA))
        limitedSpeedB = self._constraint(abs(speedB))

        limitedSpeedA += COMPENSATION_A
        limitedSpeedB += COMPENSATION_B

        #Clockwise
        if speedA > 0:
            self._motorA.setSpeed(direction="CW", pwm=abs(limitedSpeedA))
        #Anti-Clockwise
        elif speedA < 0: 
            self._motorA.setSpeed(direction="CCW", pwm=abs(limitedSpeedA))
        #Stop        
        else:
            self._motorA.setSpeed()

        #Clockwise
        if speedB > 0:
            self._motorB.setSpeed(direction="CW", pwm=abs(limitedSpeedB))
        #Anti-Clockwise
        elif speedB < 0: 
            self._motorB.setSpeed(direction="CCW", pwm=abs(limitedSpeedB))
        #Stop        
        else:
            self._motorB.setSpeed() 

        if (self.debug & MODULE_MOTION):
            #logging.debug(("Motor speed: A: %0.2f, B: %0.2f" % (speedA, speedB)))
            logging.debug(("Motor speed [LIMITED]: A: %0.2f, B: %0.2f" % (limitedSpeedA, limitedSpeedB)))

    def motorStart(self):
        '''Start motor speed stopped'''
        self._motorA.start()
        self._motorB.start()

    def motorStop(self):
        '''Set motor speed to zero, it is not necessary to restart the motor'''
        self._motorA.stop()
        self._motorB.stop()

    def motorShutDown(self):
        '''Disable motor pwm, it is necessary to restart the motor by motor.start()'''
        self._motorA.shutdown()
        self._motorB.shutdown()

    def convertRange(self, analogValue):
        '''Convert analog value (+1.0 ~ -1.0) to dutyCycle (100.0% ~ -100.0%)'''
        if not analogValue >= ANALOG_MIN and analogValue <= ANALOG_MAX:        
            logging.warning("Value out of the range (Max:1.0, Min:-1.0)")
            if analogValue > ANALOG_MAX:
                analogValue = ANALOG_MAX
            elif analogValue < ANALOG_MIN:
                analogValue = ANALOG_MIN
        return analogValue * 100.0 

    def _constraint(self, value, upperLimit=PWM_MAX, lowerLimit=PWM_MIN):        
        '''Limitation of the motor velocity'''
        #Ensure the data is into an acceptable range
        if value > upperLimit:
            value = upperLimit
        elif value < lowerLimit:
            value = lowerLimit
        return value 

def TestMotion():
    try:
        setVerbosity("debug")
        motion = Motion() 

        LP = 0.1

        while True:
            v = float((input("Inser PWM duty cycle: ")))
            motion.motorMove(v, v)            
            for i in range(25):
                motion.updateWheelVelocity(dt=LP)
                velo = motion.getWheelVelocity()
                print("wheelVelocity Average: %0.2f, A: %0.2f, B: %0.2f" % (motion.wheelVelocityAvg, motion.wheelVelocityA, motion.wheelVelocityB))
                print ("wheelVelocity : [%0.2f cm/s] [%0.2f m/s] [%0.2f km/h]" % (velo, velo/100, (velo/100)*3.6))
                print "Distance: " + str(motion.getDistance())
                time.sleep(LP)

    except KeyboardInterrupt:
        print "Shutdown motor"
        motion.motorShutDown()

if __name__ == '__main__':
    TestMotion()

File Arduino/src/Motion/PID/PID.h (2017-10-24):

/**
*************************************************
* @Project: Self Balance
* @Platform: Arduino Nano ATmega328
* @Description: PID
* @Owner: Guilherme Chinellato
* @Email: guilhermechinellato@gmail.com
*************************************************
*/


#ifndef PID_H
#define PID_H

#define SPEED_SETPOINT		0.0
#define SPEED_KP 			0.0
#define SPEED_KI 			0.0
#define SPEED_KD 			0.0
#define ANGLE_SETPOINT 		0.0
#define ANGLE_LIMIT 		0.0
#define ANGLE_KP_AGGR 		0.0
#define ANGLE_KI_AGGR 		0.0
#define ANGLE_KD_AGGR 		0.0
#define ANGLE_KP_CONS 		2.0
#define ANGLE_KI_CONS 		0.0
#define ANGLE_KD_CONS 		0.0
#define ANGLE_IRRECOVERABLE 45.0
#define CALIBRATED_ZERO_ANGLE 0.0
#define WINDUP_GUARD 		100

enum PIDTuning {CONSERVATIVE, AGGRESSIVE};

class PID
{
public:
	PID();
	float compute (float input);
    void setSetpoint(float setpoint);
    float getSetpoint();
    void setTunings(float Kp, float Ki, float Kd);
private:
	float lastError;
	unsigned long lastTime;
    float setpoint;
    float Cp;
    float Ci;
    float Cd;
    float Kp;
    float Ki;
    float Kd;
};

#endif

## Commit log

2016-05-17 first delivery
    [Frame.SLDASM, Placa-inferior.SLDDRW, Placa-inferior.SLDPRT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]
2016-05-22 pan tilt fix, tracking fix
    Pan Tilt Fix: getAbsoluteAngles and getRelative angles
    Tracking Fix: thread is not blocking anymore
    [calcs.ods]
2016-05-26 panTilt pwm hw examples
2016-05-26 motion api VNH2SP30
    [transistor-board-5v.ods]
2016-05-27 panTilt api with servoblaster
2016-05-27 panTilt thread
    Change panTilt to thread insted of process
    [transistor-board-5v.ods]
2016-06-17 Updated Motion module and folder structure
    -Motion module: Updated motor driver VNH2SP30 module test
    - Folder structure: Changed Balance and computervision paths
    [calcs-transistor.xls]
2016-06-28 Update: Motion module - VNH2SP30 driver
    [calcs-transistor.xls]
2016-06-30 Updated: Balance, CV module and GUI Test
    Balance Module: Set PID constants
    CV Module: Fix for findHSV function
    GUI Test: Implemented a GUI with client/server UDP to monitor the target
    [calcs-panTilt.ods]
2016-07-01 New implementations
    - Debug module level (Max 32 modules)
    - Callback UDP Cliente: putMessage
    - CV fix: division by zero
    [Adafruit_I2C.py]
2016-07-03 New implementations
    - Verbosity level
    - Module debug level
    - GPIO mapping file
    - Read encoders
2016-07-09 New implementations
    - Created PID module (new class)
    - Created Motor module (new class)
    - Created Encoder module (new class)
    - Update files dependents from these new ones
2016-10-01 Implemented Arduino Balance Module
    Replaced Balance thread by Arduino.
    Arduino modules:
    - IMU (GY80: Accel, Mag, Gyro, Barom)
    - Motion (Encoder, Motor, PID)
    [GY80.cpp, GY80_ADXL345.cpp, GY80_HMC5883L.cpp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]
2016-10-01 Implemented Arduino PID, Motor, IMU modules
2016-10-03 Updated Arduino and implemented Serial module
    Arduino:
    - Serial module
    - Main thread (read serial, sensors, encoders, compute PID and set PWM)
    Raspberry
    - Serial thread
2017-10-19 PID updates
2017-10-24 log file thread
2017-10-24 pantilt servoblaster config - only two servos
2017-10-24 arduino update
